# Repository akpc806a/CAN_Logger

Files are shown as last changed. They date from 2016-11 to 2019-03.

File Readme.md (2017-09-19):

# CAN Bus Logger / Playback Device with SD-card

The device can be used to log data from any CAN-bus based application: vehicle, automation, robotics, etc. The log is stored in comma separated text file (CSV) and each log entry (CAN-message) has a time stamp. It also has playback function, i.e. can play recorded file back onto a CAN bus, turning the device into a CAN bus simulator. The logger is an ideal solution for applications where small, cheap and simple device is needed to record CAN-bus activity without any additional hardware.

## Features

- The device has only one start/stop button, and all the settings are stored in configuration text file on SD card. No external PC or smartphone is required for logger operation.
- Bitrates up to 1 Mbps (any non-standard baud rate supported), supports CAN 2.0A (11-Bit ID) and CAN 2.0B (29-Bit ID).
- Optional message filtering based on ID mask matching.
- Selectable listen-only mode (without CAN bus acknowledge).
- Three LEDs for indication of logger status.
- Playback function with time accuracy of 3 ms.
- Open source and open hardware project.

## Specification

- Support for up to 32GB micro-SD cards (FAT32), for best results the UHS Speed Class 1 (U1) SD card recommended.
- Power supply voltage: from +5V to +20V DC.
- Dimensions: 48.26 x 20.85 mm (1.9 x 0.82 in).
- Microcontroller: STM32F405RGT6 (ARM Cortex M4).

## Where to buy ready made device

- [My Tindie store](https://www.tindie.com/products/akpc806a/can-bus-logger-with-sd-card/)
- [eBay](https://www.ebay.com/sch/i.html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)

N|Solid

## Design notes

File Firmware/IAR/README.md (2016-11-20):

This is project for IAR 6.50.3.4757 based on ChibiOS 2.6.7 RTOS for CAN bus logger

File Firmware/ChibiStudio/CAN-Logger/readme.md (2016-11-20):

How to build:
- download and install ChibiStudio_Preview17
- place project to [ChibiStudio]\chibios161\demos\STM32
- launch "Chibi Studio GCC 4.9"
- File>Import, select General>Existing Projects into Workspace, click Next
- Select root directory, Browse... point to project folder [ChibiStudio]\chibios161\demos\STM32
- check CAN-Logger, click Finish
- wait a little bit until Eclipse recognizes the project
- right click: Build project

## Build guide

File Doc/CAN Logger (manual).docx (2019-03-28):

# CAN Bus logger with SD-card

# 1. What is it?

This is just simple logger which writes everything from CAN bus to text file on a micro SD card. It has following features:

      - Easy to use: Only one start/stop button and all the settings are stored in configuration text file on the SD card.
      - Optional message filtering based on ID mask matching.
      - Selectable listen-only mode (without CAN bus acknowledge).
      - Three LEDs for indication of logger.

Device specification:

Parameter | Value
Power supply voltage | 5.5V-20V
Current consumption | 60mA at 5V input
CAN baudrate | up to 1Mbps (any non-standard baudrate supported)
CAN ID mask filters | 1
Microcontroller | STM32F405RGT6
CAN transceiver | SN65HVD232DR
PCB size | 48.26 mm x 20.85 mm (1.9 in x 0.82 in)

Board connections:

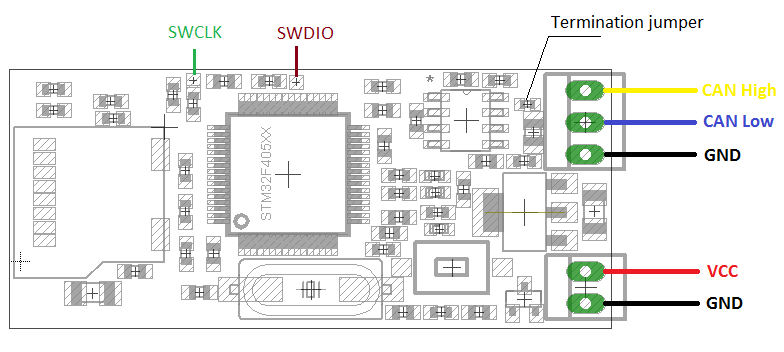
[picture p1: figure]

LEDs:

- Green: power on, also toggling every time when the CAN receives and accepts messages.
- Blue: blinks each time when block of data has been written to the SD card.
- Red: fault indication (see below).

# 2. How to start

- Connect CAN bus.
- Connect power supply (make sure the correct voltage range).
- Place Config.txt file to the root folder of SD card (here is example (https://raw.githubusercontent.com/akpc806a/CAN_Logger/master/Doc/Test/Config.txt) of the file for ODB). It is recommended to choose fastest SD card (UHS Speed Class 1 / U1) and format SD card before use in logger.
- Insert SD card.
- Press "START" button to start log
- The blue LED should blinkperiodically (with speed dependant from writing rate).
- Press "START" button again to stop the log.
- The log file placed to root folder and has name in format: N.csv, where N is number between 0 and 99999999. The next time logger will increment a file name number and write to N+1.csv, for example if there are files 0.csv, 1.csv and 2.csv, then the next written file will be 3.csv.

# 3. Configuration file format

Parameter | Parameter format | Meaning
baud | Decimal | CAN bus baudrate in kbps
ack_en | 0 or 1 | If 1 then CAN logger is responding with ACK slot on reception of a valid CAN frame. Set to 0 for silent (listen-only) mode.
id_filter_mask | Hex | Bit mask for ID filtering
id_filter_value | Hex | Expected value for ID
log_std | 0 or 1 | Messages with standard (11 bit) ID are accepted if set to 1
log_ext | 0 or 1 | Messages with extended (24 bit) ID are accepted if set to 1
timestamp | 0 or 1 | If 1 then every record in log file has a timestamp (in milliseconds)
circular_write | 0 or 1 | This will delete oldest file if there is less than 10% of free space on disk (please be aware of possible logging gap up about to 1s)
start_on_power | 0 or 1 | Recording will start immediately on power on (no push button needed)
start_on_CAN | 0 or 1 | This will start logging when a CAN message with specific ID has been received (please give about 50-100ms to prepare file on disk for record)
stop_on_CAN | 0 or 1 | This will stop logging when a CAN message with specific ID has been received
start_frame_to_name | 0 or 1 | The data of the CAN message will be used for file name
start_id_value | 0 or 1 | Bit mask of ID filtering for CAN frame which starts logging
start_id_mask | 0 or 1 | Expected value of ID for CAN frame which starts logging
stop_id_value | 0 or 1 | Bit mask of ID filtering for CAN frame which stops logging
stop_id_mask | 0 or 1 | Expected value of ID for CAN frame which stops logging

Only baud is required, all other configuration parameters are optional (and equal to 0 by default).

The ID filter acceptance criterion is:

[CAN message ID] & id_filter_mask = id_filter_value & id_filter_mask

where & is bitwise logical and operator.

For example if id_filter_mask = A = 1010 binary and the id_filter_value = 2 = 0010 binary. It means that the bit #1 and bit #3 of CAN identifier will be checked, and the bit #1 is expected to be 1 and bit #3 to be 0. Thus only identifiers with a binary ending of …0X1X will be accepted by CAN1, i.e. in hex 0x?2, 0x?3, 0x?6, 0x?7.

Set id_filter_mask= 0 to disable the ID filter.

A message with specific ID will initiate start of logging when start_on_CAN defined to 1 and following is true:

[CAN message ID] & start_id_mask = start_id_value & start_id_mask

where & is bitwise logical and operator.

A message with specific ID will stop logging when stop_on_CAN defined to 1 and following is true:

[CAN message ID] & stop_id_mask = stop_id_value & stop_id_mask

where & is bitwise logical and operator.

The option start_frame_to_name can be used in conjunction with start_on_CAN. The lower 4 bits of all data bytes from the starting CAN message will form a new file name of log file. For example if the data for start CAN message defined by ID with start_id_value/start_id_mask is = {0x01, 0x02, 0x03, 0x04, 0x05, 0x06, 0x07, 0x08}, then the new file name will be 12345678.csv;

# 4. Log file format

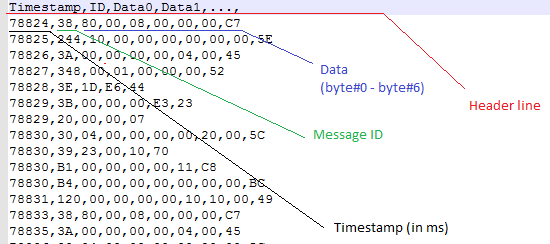
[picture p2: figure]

# 5. Faults and indication

- If red LED and blue LED are both on just after pressing "START" button, then this is a configuration text file problem; check configuration file.
- If red LED is on during logging, then this is either data buffer overflow or SD card problem. Check if there is enough free space on SD card or SD card has acceptable writing speed rate.

# 6. CAN bus termination

Please note that the 120 ohm termination resistor is permanently placed on board. There is no configurable option for it. However, there is a jumper as 0402 resistor which is possible to unmount for termination disconnection.

If the bus already has termination at the both ends, then you may consider removing on-board termination. However, for most application it’s ok to leave it (for example when connecting to vehicle OBD-II diagnostic connector).

# 7. CAN bus simulator (playback from file)

There is an experimental function implemented to play back recorded data onto a CAN bus, turning device into a CAN bus simulator.

Place recorded log to SD card root folder, rename it to Play.csv. Press "START" button, the device will read Play.csv file line by line and transmit all recorded CAN messages back to the bus. After completion of transmission the device will be switched to standard logger mode.

- Playback file will be transmitted with the baudrate from Config.txt file.

- Playback file should be time-stamped (i.e. recorded with timestamp=1 option).

- Playback file should contain a header, i.e. first line of the file will be skipped.

- By default, all messages will be send out using standard (11-bit) identifier, if the identifier value from file fits into 11 bit, otherwise it will be send as 24 bit (if it does require more than 11 bits)

- You can enforce the usage of extended identifiers only by setting log_std=0 in Config.txt

- The green LED will be off during playback, the blue LED will toggle every time when the message has been sent, red LED will be on if any faults occurred.

Limitations:

- All messages should be acknowledged from the CAN bus side.

- It is not exactly time accurate because timestamp has 1 ms granularity.

- The only way to exit playback mode in case if it’s stuck (for example due to bus fault), is to power cycle the device.

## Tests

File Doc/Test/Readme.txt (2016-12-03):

This is use case data for OBD-II diagnostic bus logging.
In parallel to the device the PCAN-USB Adapter (by PACN / Grid Connect) was connected and logging performed using PcanView software. Logging to SD card was started first, so there is portion of data at the beginning which is absent in PCAN log.
Then both logs were post-processed and compared with WinMerge. You can check the screenshot WinMerge.png of comparision.
No difference has been found.
The 'Config.txt' file used to configure logger device included.

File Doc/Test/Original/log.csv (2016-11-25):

Timestamp,ID,Data0,Data1,...,
78824,38,80,00,08,00,00,00,C7
78825,244,10,00,00,00,00,00,00,5E
78826,3A,00,00,00,00,04,00,45
78827,348,00,01,00,00,00,52
78828,3E,1D,E6,44
78829,3B,00,00,00,E3,23
78829,20,00,00,07
78830,30,04,00,00,00,00,20,00,5C
78830,39,23,00,10,70
78830,B1,00,00,00,00,11,C8
78830,B4,00,00,00,00,00,00,00,BC
78831,120,00,00,00,00,10,10,00,49
78833,38,80,00,08,00,00,00,C7
78835,3A,00,00,00,00,04,00,45
78836,30,04,00,00,00,00,20,00,5C
78837,B3,00,00,00,00,11,CA
78837,3E,1D,E6,44
78837,3B,00,00,00,E3,23
78838,39,23,00,10,70
78841,38,80,00,08,00,00,00,C7
78841,3CA,00,20,00,00,F2
78842,262,00,01,00,69
78842,20,00,00,07
78843,30,04,00,00,00,00,20,00,5C
78843,3A,00,00,00,00,04,00,45
78843,B1,00,00,00,00,11,C8
78843,B4,00,00,00,00,00,00,00,BC
78844,230,00,05,00,00,00,00,3E
78845,3E,1D,E6,44
78845,3B,00,00,00,E3,23
78846,39,23,00,10,70
78847,120,00,00,00,00,10,10,00,49
78847,3C8,00,34,00,00,04
78849,38,80,00,08,00,00,00,C7
78849,30,04,00,00,00,00,20,00,5C
78849,B3,00,00,00,00,11,CA
78850,244,10,00,00,00,00,00,00,5E
78851,3A,00,00,00,00,04,00,45
78853,3E,1D,E6,44
78853,3B,00,00,00,E3,23
78854,39,23,00,10,70
78855,20,00,00,07
78855,30,04,00,00,00,00,20,00,5C
78855,B1,00,00,00,00,11,C8
78856,B4,00,00,00,00,00,00,00,BC
78857,38,80,00,08,00,00,00,C7
78857,3CF,10,0F,1D,00,13
78859,3A,00,00,00,00,04,00,45
78861,3E,1D,E6,44
78861,3B,00,00,00,E3,23
78862,30,04,00,00,00,00,20,00,5C
78862,B3,00,00,00,00,11,CA
78862,262,00,01,00,69
78863,39,23,00,10,70
78863,120,00,00,00,00,10,10,00,49
78865,38,80,00,08,00,00,00,C7
78867,3A,00,00,00,00,04,00,45
78868,348,00,01,00,00,00,52
78868,20,00,00,07
78868,30,04,00,00,00,00,20,00,5C
78868,B1,00,00,00,00,11,C8
78868,B4,00,00,00,00,00,00,00,BC
78869,230,00,05,00,00,00,00,3E
78869,3B,00,00,00,E4,24
78869,3E,1D,E6,44
78871,39,23,00,10,70
78873,3C9,03,FF,21,02,9B,03,21,B8
78874,38,80,00,08,00,00,00,C7
78874,244,10,00,00,00,00,00,00,5E
78874,30,04,00,00,00,00,20,00,5C
78875,B3,00,00,00,00,11,CA
78876,3A,00,00,00,00,04,00,45
78877,3B,00,00,00,E4,24
78878,3E,1D,E6,44
78879,39,23,00,10,70
78880,120,00,00,00,00,10,10,00,49
78880,20,00,00,07
78881,30,04,00,00,00,00,20,00,5C
78881,B1,00,00,00,00,11,C8
78881,B4,00,00,00,00,00,00,00,BC
78881,3CB,64,64,00,81,11,10,3F
78882,38,80,00,08,00,00,00,C7
78882,521,23,00
78883,262,00,01,00,69
78884,3A,00,00,00,00,04,00,45
78885,3B,00,00,00,E3,23
78886,3E,1D,E6,44
78887,39,23,00,10,70
78887,30,04,00,00,00,00,20,00,5C
78888,B3,00,00,00,00,11,CA
78889,3CD,00,00,00,E2,B7
78890,38,80,00,08,00,00,00,C7
78892,3A,00,00,00,00,04,00,45
78893,20,00,00,07
78893,30,04,00,00,00,00,20,00,5C
78894,3B,00,00,00,E3,23
78894,B1,00,00,00,00,11,C8
78894,3E,1D,E6,44
78894,B4,00,00,00,00,00,00,00,BC
78894,230,00,05,00,00,00,00,3E
78895,554,58,41,42,4C,41,45,4E
78895,39,23,00,10,70
78896,120,00,00,00,00,10,10,00,49
78898,38,80,00,08,00,00,00,C7
78898,244,10,00,00,00,00,00,00,5E
78900,30,04,00,00,00,00,20,00,5C
78900,3A,00,00,00,00,04,00,45
78900,B3,00,00,00,00,11,CA
78901,3B,00,00,00,E3,23
78902,3E,1D,E6,44
78902,262,00,01,00,69
78903,39,23,00,10,70
78906,20,00,00,07
78906,30,04,00,00,00,00,20,00,5C
78906,38,80,00,08,00,00,00,C7
78907,B1,00,00,00,00,11,C8
78907,B4,00,00,00,00,00,00,00,BC
78908,3A,00,00,00,00,04,00,45
78909,348,00,01,00,00,00,52
78909,3B,00,00,00,E4,24
78910,3E,1D,E6,44
78912,39,23,00,10,70
78912,120,00,00,00,00,10,10,00,49
78913,30,04,00,00,00,00,20,00,5C
78913,B3,00,00,00,00,11,CA
78913,3C8,00,34,00,00,04
78915,38,80,00,08,00,00,00,C7
78917,3A,00,00,00,00,04,00,45
78917,3B,00,00,00,E4,24
78919,3E,1D,E6,44
78919,20,00,00,07
78919,30,04,00,00,00,00,20,00,5C
78919,B1,00,00,00,00,11,C8
78919,B4,00,00,00,00,00,00,00,BC
78920,230,00,05,00,00,00,00,3E
78920,39,23,00,10,70
78920,553,58,49,00,08,00,00,00
78922,262,00,01,00,69
78923,38,80,00,08,00,00,00,C7
78923,244,10,00,00,00,00,00,00,5E
78925,3A,00,00,00,00,04,00,45
78925,3B,00,00,00,E3,23
78926,30,04,00,00,00,00,20,00,5C
78926,B3,00,00,00,00,11,CA
78927,3E,1D,E6,44
78928,39,23,00,10,70
78929,120,00,00,00,00,10,10,00,49
78931,38,80,00,08,00,00,00,C7
78931,20,00,00,07
78932,30,04,00,00,00,00,20,00,5C
78932,B1,00,00,00,00,11,C8
78932,B4,00,00,00,00,00,00,00,BC
78933,3A,00,00,00,00,04,00,45
78933,3B,00,00,00,E3,23
78935,3E,1D,E6,44
78936,39,23,00,10,70
78938,30,04,00,00,00,00,20,00,5C
78938,B3,00,00,00,00,11,CA
78939,38,80,00,08,00,00,00,C7
78941,3A,00,00,00,00,04,00,45
78941,3B,00,00,00,E3,23
78941,3CA,00,20,00,00,F2
78942,262,00,01,00,69
78943,3E,1D,E6,44
78944,20,00,00,07
78944,30,04,00,00,00,00,20,00,5C
78945,39,23,00,10,70
78945,B1,00,00,00,00,11,C8
78945,B4,00,00,00,00,00,00,00,BC
78945,120,00,00,00,00,10,10,00,49
78946,230,00,05,00,00,00,00,3E
78946,4D0,10,00,02,02,00,00,00,00
78947,38,80,00,08,00,00,00,C7
78948,244,10,00,00,00,00,00,00,5E
78949,3A,00,00,00,00,04,00,45
78949,3B,00,00,00,E3,23
78950,348,00,01,00,00,00,52
78951,30,04,00,00,00,00,20,00,5C
78951,B3,00,00,00,00,11,CA
78951,3E,1D,E6,44
78953,39,23,00,10,70
78955,38,80,00,08,00,00,00,C7
78957,20,00,00,07
78957,30,04,00,00,00,00,20,00,5C
78957,3A,00,00,00,00,04,00,45
78958,3B,00,00,00,E3,23
78958,B1,00,00,00,00,11,C8
78958,B4,00,00,00,00,00,00,00,BC
78959,3E,1D,E6,44
78961,39,23,00,10,70
78962,120,00,00,00,00,10,10,00,49
78962,262,00,01,00,69
78964,38,80,00,08,00,00,00,C7
78964,30,04,00,00,00,00,20,00,5C
78964,B3,00,00,00,00,11,CA
78965,3B,00,00,00,E4,24
78966,3A,00,00,00,00,04,00,45
78968,3E,1D,E6,44
78969,39,23,00,10,70
78970,20,00,00,07
78970,30,04,00,00,00,00,20,00,5C
78970,B1,00,00,00,00,11,C8
78970,B4,00,00,00,00,00,00,00,BC
78971,230,00,05,00,00,00,00,3E
78972,38,80,00,08,00,00,00,C7
78972,244,10,00,00,00,00,00,00,5E
78973,56D,65,68,80,7F
78973,3B,00,00,00,E4,24
78974,3C9,03,FF,21,02,9B,03,21,B8
78974,3A,00,00,00,00,04,00,45
78976,3E,1D,E6,44
78976,30,04,00,00,00,00,20,00,5C
78977,B3,00,00,00,00,11,CA
78977,39,23,00,10,70
78978,120,00,00,00,00,10,10,00,49
78978,3C8,00,34,00,00,04
78980,38,80,00,08,00,00,00,C7
78981,3B,00,00,00,E4,24
78982,3CB,64,64,00,81,11,10,3F
78982,3A,00,00,00,00,04,00,45
78982,20,00,00,07
78983,30,04,00,00,00,00,20,00,5C
78983,B1,00,00,00,00,11,C8
78983,B4,00,00,00,00,00,00,00,BC
78983,262,00,01,00,69
78984,3E,1D,E6,44
78985,39,23,00,10,70
78987,52C,23,46
78988,38,80,00,08,00,00,00,C7
78988,3CF,10,0F,1D,00,13
78989,30,04,00,00,00,00,20,00,5C
78990,3B,00,00,00,E3,23
78990,B3,00,00,00,00,11,CA
78990,3CD,00,00,00,E3,B8
78990,3A,00,00,00,00,04,00,45
78991,348,00,01,00,00,00,52
78992,3E,1D,E6,44
78994,39,23,00,10,70
78994,120,00,00,00,00,10,10,00,49
78995,20,00,00,07
78996,30,04,00,00,00,00,20,00,5C
78996,B1,00,00,00,00,11,C8
78996,B4,00,00,00,00,00,00,00,BC
78996,230,00,05,00,00,00,00,3E
78996,38,80,00,08,00,00,00,C7
78997,244,10,00,00,00,00,00,00,5E
78997,3B,00,00,00,E3,23
78998,5D4,23,00
78998,3A,00,00,00,00,04,00,45
79000,3E,1D,E6,44
79002,39,23,00,10,70
79002,30,04,00,00,00,00,20,00,5C
79002,B3,00,00,00,00,11,CA
79002,262,00,01,00,69
79005,38,80,00,08,00,00,00,C7
79005,3B,00,00,00,E3,23
79007,3A,00,00,00,00,04,00,45
79007,5F8,23,04
79008,20,00,00,07
79008,30,04,00,00,00,00,20,00,5C
79008,B1,00,00,00,00,11,C8
79009,B4,00,00,00,00,00,00,00,BC
79009,3E,1D,E6,44
79010,39,23,00,10,70
79011,120,00,00,00,00,10,10,00,49
79013,38,80,00,08,00,00,00,C7
79013,3B,00,00,00,E4,24
79015,30,04,00,00,00,00,20,00,5C
79015,3A,00,00,00,00,04,00,45
79015,B3,00,00,00,00,11,CA
79017,3E,1D,E6,44
79018,39,23,00,10,70
79021,20,00,00,07
79021,30,04,00,00,00,00,20,00,5C
79021,38,80,00,08,00,00,00,C7
79021,3B,00,00,00,E4,24
79022,B1,00,00,00,00,11,C8
79022,B4,00,00,00,00,00,00,00,BC
79022,244,10,00,00,00,00,00,00,5E
79022,230,00,05,00,00,00,00,3E
79022,262,00,01,00,69
79023,3A,00,00,00,00,04,00,45
79025,3E,1D,E6,44
79026,39,23,00,10,70
79027,120,00,00,00,00,10,10,00,49
79027,30,04,00,00,00,00,20,00,5C
79028,B3,00,00,00,00,11,CA
79029,38,80,00,08,00,00,00,C7
79029,3B,00,00,00,E3,23
79031,3A,00,00,00,00,04,00,45
79031,348,00,01,00,00,00,52
79033,3E,1D,E6,44
79033,20,00,00,07
79034,30,04,00,00,00,00,20,00,5C
79034,B1,00,00,00,00,11,C8
79034,B4,00,00,00,00,00,00,00,BC
79035,39,23,00,10,70
79037,38,80,00,08,00,00,00,C7
79038,3B,00,00,00,E3,23
79039,3A,00,00,00,00,04,00,45
79040,30,04,00,00,00,00,20,00,5C
79041,B3,00,00,00,00,11,CA
79041,3E,1D,E6,44
79042,3CA,00,20,00,00,F2
79042,262,00,01,00,69
79043,39,23,00,10,70
79044,120,00,00,00,00,10,10,00,49
79044,3C8,00,34,00,00,04
79045,3B,00,00,00,E3,23
79046,38,80,00,08,00,00,00,C7
79046,244,10,00,00,00,00,00,00,5E
79046,20,00,00,07
79046,30,04,00,00,00,00,20,00,5C
79047,B1,00,00,00,00,11,C8
79047,B4,00,00,00,00,00,00,00,BC
79047,230,00,05,00,00,00,00,3E
79048,3A,00,00,00,00,04,00,45
79050,3E,1D,E6,44
79051,39,23,00,10,70
79053,30,04,00,00,00,00,20,00,5C
79053,B3,00,00,00,00,11,CA
79053,3B,00,00,00,E3,23
79054,38,80,00,08,00,00,00,C7
79056,3A,00,00,00,00,04,00,45
79058,3E,1D,E6,44
79059,20,00,00,07
79059,30,04,00,00,00,00,20,00,5C
79059,39,23,00,10,70
79060,B1,00,00,00,00,11,C8
79060,B4,00,00,00,00,00,00,00,BC
79060,120,00,00,00,00,10,10,00,49
79061,3B,00,00,00,E3,23
79062,38,80,00,08,00,00,00,C7
79062,262,00,01,00,69
79064,3A,00,00,00,00,04,00,45
79066,30,04,00,00,00,00,20,00,5C
79066,B3,00,00,00,00,11,CA
79066,3E,1D,E6,44
79067,39,23,00,10,70
79069,3B,00,00,00,E4,24
79070,38,80,00,08,00,00,00,C7
79070,244,10,00,00,00,00,00,00,5E
79072,20,00,00,07
79072,30,04,00,00,00,00,20,00,5C
79072,3A,00,00,00,00,04,00,45
79072,B1,00,00,00,00,11,C8
79073,B4,00,00,00,00,00,00,00,BC
79073,348,00,01,00,00,00,52
79073,230,00,05,00,00,00,00,3E
79073,3C9,03,FF,21,02,9B,03,21,B8
79074,3E,1D,E6,44
79074,5CC,24,01,C0
79076,39,23,00,10,70
79076,120,00,00,00,00,10,10,00,49
79077,3B,00,00,00,E4,24
79078,30,04,00,00,00,00,20,00,5C
79079,38,80,00,08,00,00,00,C7
79079,B3,00,00,00,00,11,CA
79080,3A,00,00,00,00,04,00,45
79081,3CB,64,64,00,81,11,10,3F
79082,262,00,01,00,69
79082,3E,1D,E6,44
79084,39,23,00,10,70
79084,20,00,00,07
79085,30,04,00,00,00,00,20,00,5C
79085,B1,00,00,00,00,11,C8
79085,B4,00,00,00,00,00,00,00,BC
79085,3B,00,00,00,E3,23
79087,38,80,00,08,00,00,00,C7
79089,3A,00,00,00,00,04,00,45
79089,3CD,00,00,00,E3,B8
79091,3E,1D,E6,44
79091,30,04,00,00,00,00,20,00,5C
79091,B3,00,00,00,00,11,CA
79092,39,23,00,10,70
79093,120,00,00,00,00,10,10,00,49
79093,3B,00,00,00,E3,23
79095,38,80,00,08,00,00,00,C7
79095,244,10,00,00,00,00,00,00,5E
79097,3A,00,00,00,00,04,00,45
79097,20,00,00,07
79097,30,04,00,00,00,00,20,00,5C
79098,B1,00,00,00,00,11,C8
79098,B4,00,00,00,00,00,00,00,BC
79098,230,00,05,00,00,00,00,3E
79099,3E,1D,E6,44
79100,39,23,00,10,70
79101,3B,00,00,00,E3,23
79102,262,00,01,00,69
79103,38,80,00,08,00,00,00,C7
79104,30,04,00,00,00,00,20,00,5C
79104,B3,00,00,00,00,11,CA
79105,3A,00,00,00,00,04,00,45
79107,3E,1D,E6,44
79108,39,23,00,10,70
79109,120,00,00,00,00,10,10,00,49
79109,3C8,00,34,00,00,04
79110,3B,00,00,00,E4,24
79110,20,00,00,07
79110,30,04,00,00,00,00,20,00,5C
79110,B1,00,00,00,00,11,C8
79111,B4,00,00,00,00,00,00,00,BC
79111,38,80,00,08,00,00,00,C7
79113,3A,00,00,00,00,04,00,45
79113,348,00,01,00,00,00,52
79115,3E,1D,E6,44
79116,39,23,00,10,70
79117,30,04,00,00,00,00,20,00,5C
79117,B3,00,00,00,00,11,CA
79117,3B,00,00,00,E3,23
79119,38,80,00,08,00,00,00,C7
79120,244,10,00,00,00,00,00,00,5E
79120,3CF,10,0F,1D,00,13
79121,3A,00,00,00,00,04,00,45
79122,262,00,01,00,69
79123,20,00,00,07
79123,30,04,00,00,00,00,20,00,5C
79123,B1,00,00,00,00,11,C8
79123,B4,00,00,00,00,00,00,00,BC
79123,3E,1D,E6,44
79124,230,00,05,00,00,00,00,3E
79125,39,23,00,10,70
79125,3B,00,00,00,E3,23
79126,120,00,00,00,00,10,10,00,49
79128,38,80,00,08,00,00,00,C7
79129,30,04,00,00,00,00,20,00,5C
79130,3A,00,00,00,00,04,00,45
79130,B3,00,00,00,00,11,CA
79130,591,25,A0,1C,06
79132,3E,1D,E6,44
79133,39,23,00,10,70
79133,3B,00,00,00,E3,23
79134,4C1,01,00,09,00,00,00,00,00
79135,20,00,00,07
79136,30,04,00,00,00,00,20,00,5C
79136,38,80,00,08,00,00,00,C7
79136,B1,00,00,00,00,11,C8
79136,B4,00,00,00,00,00,00,00,BC
79138,3A,00,00,00,00,04,00,45
79140,3E,1D,E6,44
79141,39,23,00,10,70
79141,3B,00,00,00,E3,23
79142,120,00,00,00,00,10,10,00,49
79142,3CA,00,20,00,00,F2
79142,30,04,00,00,00,00,20,00,5C
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

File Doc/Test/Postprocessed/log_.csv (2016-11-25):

0038,80,00,08,00,00,00,C7
0244,10,00,00,00,00,00,00,5E
003A,00,00,00,00,04,00,45
0348,00,01,00,00,00,52
003E,1D,E6,44
003B,00,00,00,E3,23
0020,00,00,07
0030,04,00,00,00,00,20,00,5C
0039,23,00,10,70
00B1,00,00,00,00,11,C8
00B4,00,00,00,00,00,00,00,BC
0120,00,00,00,00,10,10,00,49
0038,80,00,08,00,00,00,C7
003A,00,00,00,00,04,00,45
0030,04,00,00,00,00,20,00,5C
00B3,00,00,00,00,11,CA
003E,1D,E6,44
003B,00,00,00,E3,23
0039,23,00,10,70
0038,80,00,08,00,00,00,C7
03CA,00,20,00,00,F2
0262,00,01,00,69
0020,00,00,07
0030,04,00,00,00,00,20,00,5C
003A,00,00,00,00,04,00,45
00B1,00,00,00,00,11,C8
00B4,00,00,00,00,00,00,00,BC
0230,00,05,00,00,00,00,3E
003E,1D,E6,44
003B,00,00,00,E3,23
0039,23,00,10,70
0120,00,00,00,00,10,10,00,49
03C8,00,34,00,00,04
0038,80,00,08,00,00,00,C7
0030,04,00,00,00,00,20,00,5C
00B3,00,00,00,00,11,CA
0244,10,00,00,00,00,00,00,5E
003A,00,00,00,00,04,00,45
003E,1D,E6,44
003B,00,00,00,E3,23
0039,23,00,10,70
0020,00,00,07
0030,04,00,00,00,00,20,00,5C
00B1,00,00,00,00,11,C8
00B4,00,00,00,00,00,00,00,BC
0038,80,00,08,00,00,00,C7
03CF,10,0F,1D,00,13
003A,00,00,00,00,04,00,45
003E,1D,E6,44
003B,00,00,00,E3,23
0030,04,00,00,00,00,20,00,5C
00B3,00,00,00,00,11,CA
0262,00,01,00,69
0039,23,00,10,70
0120,00,00,00,00,10,10,00,49
0038,80,00,08,00,00,00,C7
003A,00,00,00,00,04,00,45
0348,00,01,00,00,00,52
0020,00,00,07
0030,04,00,00,00,00,20,00,5C
00B1,00,00,00,00,11,C8
00B4,00,00,00,00,00,00,00,BC
0230,00,05,00,00,00,00,3E
003B,00,00,00,E4,24
003E,1D,E6,44
0039,23,00,10,70
03C9,03,FF,21,02,9B,03,21,B8
0038,80,00,08,00,00,00,C7
0244,10,00,00,00,00,00,00,5E
0030,04,00,00,00,00,20,00,5C
00B3,00,00,00,00,11,CA
003A,00,00,00,00,04,00,45
003B,00,00,00,E4,24
003E,1D,E6,44
0039,23,00,10,70
0120,00,00,00,00,10,10,00,49
0020,00,00,07
0030,04,00,00,00,00,20,00,5C
00B1,00,00,00,00,11,C8
00B4,00,00,00,00,00,00,00,BC
03CB,64,64,00,81,11,10,3F
0038,80,00,08,00,00,00,C7
0521,23,00
0262,00,01,00,69
003A,00,00,00,00,04,00,45
003B,00,00,00,E3,23
003E,1D,E6,44
0039,23,00,10,70
0030,04,00,00,00,00,20,00,5C
00B3,00,00,00,00,11,CA
03CD,00,00,00,E2,B7
0038,80,00,08,00,00,00,C7
003A,00,00,00,00,04,00,45
0020,00,00,07
0030,04,00,00,00,00,20,00,5C
003B,00,00,00,E3,23
00B1,00,00,00,00,11,C8
003E,1D,E6,44
00B4,00,00,00,00,00,00,00,BC
0230,00,05,00,00,00,00,3E
0554,58,41,42,4C,41,45,4E
0039,23,00,10,70
0120,00,00,00,00,10,10,00,49
0038,80,00,08,00,00,00,C7
0244,10,00,00,00,00,00,00,5E
0030,04,00,00,00,00,20,00,5C
003A,00,00,00,00,04,00,45
00B3,00,00,00,00,11,CA
003B,00,00,00,E3,23
003E,1D,E6,44
0262,00,01,00,69
0039,23,00,10,70
0020,00,00,07
0030,04,00,00,00,00,20,00,5C
0038,80,00,08,00,00,00,C7
00B1,00,00,00,00,11,C8
00B4,00,00,00,00,00,00,00,BC
003A,00,00,00,00,04,00,45
0348,00,01,00,00,00,52
003B,00,00,00,E4,24
003E,1D,E6,44
0039,23,00,10,70
0120,00,00,00,00,10,10,00,49
0030,04,00,00,00,00,20,00,5C
00B3,00,00,00,00,11,CA
03C8,00,34,00,00,04
0038,80,00,08,00,00,00,C7
003A,00,00,00,00,04,00,45
003B,00,00,00,E4,24
003E,1D,E6,44
0020,00,00,07
0030,04,00,00,00,00,20,00,5C
00B1,00,00,00,00,11,C8
00B4,00,00,00,00,00,00,00,BC
0230,00,05,00,00,00,00,3E
0039,23,00,10,70
0553,58,49,00,08,00,00,00
0262,00,01,00,69
0038,80,00,08,00,00,00,C7
0244,10,00,00,00,00,00,00,5E
003A,00,00,00,00,04,00,45
003B,00,00,00,E3,23
0030,04,00,00,00,00,20,00,5C
00B3,00,00,00,00,11,CA
003E,1D,E6,44
0039,23,00,10,70
0120,00,00,00,00,10,10,00,49
0038,80,00,08,00,00,00,C7
0020,00,00,07
0030,04,00,00,00,00,20,00,5C
00B1,00,00,00,00,11,C8
00B4,00,00,00,00,00,00,00,BC
003A,00,00,00,00,04,00,45
003B,00,00,00,E3,23
003E,1D,E6,44
0039,23,00,10,70
0030,04,00,00,00,00,20,00,5C
00B3,00,00,00,00,11,CA
0038,80,00,08,00,00,00,C7
003A,00,00,00,00,04,00,45
003B,00,00,00,E3,23
03CA,00,20,00,00,F2
0262,00,01,00,69
003E,1D,E6,44
0020,00,00,07
0030,04,00,00,00,00,20,00,5C
0039,23,00,10,70
00B1,00,00,00,00,11,C8
00B4,00,00,00,00,00,00,00,BC
0120,00,00,00,00,10,10,00,49
0230,00,05,00,00,00,00,3E
04D0,10,00,02,02,00,00,00,00
0038,80,00,08,00,00,00,C7
0244,10,00,00,00,00,00,00,5E
003A,00,00,00,00,04,00,45
003B,00,00,00,E3,23
0348,00,01,00,00,00,52
0030,04,00,00,00,00,20,00,5C
00B3,00,00,00,00,11,CA
003E,1D,E6,44
0039,23,00,10,70
0038,80,00,08,00,00,00,C7
0020,00,00,07
0030,04,00,00,00,00,20,00,5C
003A,00,00,00,00,04,00,45
003B,00,00,00,E3,23
00B1,00,00,00,00,11,C8
00B4,00,00,00,00,00,00,00,BC
003E,1D,E6,44
0039,23,00,10,70
0120,00,00,00,00,10,10,00,49
0262,00,01,00,69
0038,80,00,08,00,00,00,C7
0030,04,00,00,00,00,20,00,5C
00B3,00,00,00,00,11,CA
003B,00,00,00,E4,24
003A,00,00,00,00,04,00,45
003E,1D,E6,44
0039,23,00,10,70
0020,00,00,07
0030,04,00,00,00,00,20,00,5C
00B1,00,00,00,00,11,C8
00B4,00,00,00,00,00,00,00,BC
0230,00,05,00,00,00,00,3E
0038,80,00,08,00,00,00,C7
0244,10,00,00,00,00,00,00,5E
056D,65,68,80,7F
003B,00,00,00,E4,24
03C9,03,FF,21,02,9B,03,21,B8
003A,00,00,00,00,04,00,45
003E,1D,E6,44
0030,04,00,00,00,00,20,00,5C
00B3,00,00,00,00,11,CA
0039,23,00,10,70
0120,00,00,00,00,10,10,00,49
03C8,00,34,00,00,04
0038,80,00,08,00,00,00,C7
003B,00,00,00,E4,24
03CB,64,64,00,81,11,10,3F
003A,00,00,00,00,04,00,45
0020,00,00,07
0030,04,00,00,00,00,20,00,5C
00B1,00,00,00,00,11,C8
00B4,00,00,00,00,00,00,00,BC
0262,00,01,00,69
003E,1D,E6,44
0039,23,00,10,70
052C,23,46
0038,80,00,08,00,00,00,C7
03CF,10,0F,1D,00,13
0030,04,00,00,00,00,20,00,5C
003B,00,00,00,E3,23
00B3,00,00,00,00,11,CA
03CD,00,00,00,E3,B8
003A,00,00,00,00,04,00,45
0348,00,01,00,00,00,52
003E,1D,E6,44
0039,23,00,10,70
0120,00,00,00,00,10,10,00,49
0020,00,00,07
0030,04,00,00,00,00,20,00,5C
00B1,00,00,00,00,11,C8
00B4,00,00,00,00,00,00,00,BC
0230,00,05,00,00,00,00,3E
0038,80,00,08,00,00,00,C7
0244,10,00,00,00,00,00,00,5E
003B,00,00,00,E3,23
05D4,23,00
003A,00,00,00,00,04,00,45
003E,1D,E6,44
0039,23,00,10,70
0030,04,00,00,00,00,20,00,5C
00B3,00,00,00,00,11,CA
0262,00,01,00,69
0038,80,00,08,00,00,00,C7
003B,00,00,00,E3,23
003A,00,00,00,00,04,00,45
05F8,23,04
0020,00,00,07
0030,04,00,00,00,00,20,00,5C
00B1,00,00,00,00,11,C8
00B4,00,00,00,00,00,00,00,BC
003E,1D,E6,44
0039,23,00,10,70
0120,00,00,00,00,10,10,00,49
0038,80,00,08,00,00,00,C7
003B,00,00,00,E4,24
0030,04,00,00,00,00,20,00,5C
003A,00,00,00,00,04,00,45
00B3,00,00,00,00,11,CA
003E,1D,E6,44
0039,23,00,10,70
0020,00,00,07
0030,04,00,00,00,00,20,00,5C
0038,80,00,08,00,00,00,C7
003B,00,00,00,E4,24
00B1,00,00,00,00,11,C8
00B4,00,00,00,00,00,00,00,BC
0244,10,00,00,00,00,00,00,5E
0230,00,05,00,00,00,00,3E
0262,00,01,00,69
003A,00,00,00,00,04,00,45
003E,1D,E6,44
0039,23,00,10,70
0120,00,00,00,00,10,10,00,49
0030,04,00,00,00,00,20,00,5C
00B3,00,00,00,00,11,CA
0038,80,00,08,00,00,00,C7
003B,00,00,00,E3,23
003A,00,00,00,00,04,00,45
0348,00,01,00,00,00,52
003E,1D,E6,44
0020,00,00,07
0030,04,00,00,00,00,20,00,5C
00B1,00,00,00,00,11,C8
00B4,00,00,00,00,00,00,00,BC
0039,23,00,10,70
0038,80,00,08,00,00,00,C7
003B,00,00,00,E3,23
003A,00,00,00,00,04,00,45
0030,04,00,00,00,00,20,00,5C
00B3,00,00,00,00,11,CA
003E,1D,E6,44
03CA,00,20,00,00,F2
0262,00,01,00,69
0039,23,00,10,70
0120,00,00,00,00,10,10,00,49
03C8,00,34,00,00,04
003B,00,00,00,E3,23
0038,80,00,08,00,00,00,C7
0244,10,00,00,00,00,00,00,5E
0020,00,00,07
0030,04,00,00,00,00,20,00,5C
00B1,00,00,00,00,11,C8
00B4,00,00,00,00,00,00,00,BC
0230,00,05,00,00,00,00,3E
003A,00,00,00,00,04,00,45
003E,1D,E6,44
0039,23,00,10,70
0030,04,00,00,00,00,20,00,5C
00B3,00,00,00,00,11,CA
003B,00,00,00,E3,23
0038,80,00,08,00,00,00,C7
003A,00,00,00,00,04,00,45
003E,1D,E6,44
0020,00,00,07
0030,04,00,00,00,00,20,00,5C
0039,23,00,10,70
00B1,00,00,00,00,11,C8
00B4,00,00,00,00,00,00,00,BC
0120,00,00,00,00,10,10,00,49
003B,00,00,00,E3,23
0038,80,00,08,00,00,00,C7
0262,00,01,00,69
003A,00,00,00,00,04,00,45
0030,04,00,00,00,00,20,00,5C
00B3,00,00,00,00,11,CA
003E,1D,E6,44
0039,23,00,10,70
003B,00,00,00,E4,24
0038,80,00,08,00,00,00,C7
0244,10,00,00,00,00,00,00,5E
0020,00,00,07
0030,04,00,00,00,00,20,00,5C
003A,00,00,00,00,04,00,45
00B1,00,00,00,00,11,C8
00B4,00,00,00,00,00,00,00,BC
0348,00,01,00,00,00,52
0230,00,05,00,00,00,00,3E
03C9,03,FF,21,02,9B,03,21,B8
003E,1D,E6,44
05CC,24,01,C0
0039,23,00,10,70
0120,00,00,00,00,10,10,00,49
003B,00,00,00,E4,24
0030,04,00,00,00,00,20,00,5C
0038,80,00,08,00,00,00,C7
00B3,00,00,00,00,11,CA
003A,00,00,00,00,04,00,45
03CB,64,64,00,81,11,10,3F
0262,00,01,00,69
003E,1D,E6,44
0039,23,00,10,70
0020,00,00,07
0030,04,00,00,00,00,20,00,5C
00B1,00,00,00,00,11,C8
00B4,00,00,00,00,00,00,00,BC
003B,00,00,00,E3,23
0038,80,00,08,00,00,00,C7
003A,00,00,00,00,04,00,45
03CD,00,00,00,E3,B8
003E,1D,E6,44
0030,04,00,00,00,00,20,00,5C
00B3,00,00,00,00,11,CA
0039,23,00,10,70
0120,00,00,00,00,10,10,00,49
003B,00,00,00,E3,23
0038,80,00,08,00,00,00,C7
0244,10,00,00,00,00,00,00,5E
003A,00,00,00,00,04,00,45
0020,00,00,07
0030,04,00,00,00,00,20,00,5C
00B1,00,00,00,00,11,C8
00B4,00,00,00,00,00,00,00,BC
0230,00,05,00,00,00,00,3E
003E,1D,E6,44
0039,23,00,10,70
003B,00,00,00,E3,23
0262,00,01,00,69
0038,80,00,08,00,00,00,C7
0030,04,00,00,00,00,20,00,5C
00B3,00,00,00,00,11,CA
003A,00,00,00,00,04,00,45
003E,1D,E6,44
0039,23,00,10,70
0120,00,00,00,00,10,10,00,49
03C8,00,34,00,00,04
003B,00,00,00,E4,24
0020,00,00,07
0030,04,00,00,00,00,20,00,5C
00B1,00,00,00,00,11,C8
00B4,00,00,00,00,00,00,00,BC
0038,80,00,08,00,00,00,C7
003A,00,00,00,00,04,00,45
0348,00,01,00,00,00,52
003E,1D,E6,44
0039,23,00,10,70
0030,04,00,00,00,00,20,00,5C
00B3,00,00,00,00,11,CA
003B,00,00,00,E3,23
0038,80,00,08,00,00,00,C7
0244,10,00,00,00,00,00,00,5E
03CF,10,0F,1D,00,13
003A,00,00,00,00,04,00,45
0262,00,01,00,69
0020,00,00,07
0030,04,00,00,00,00,20,00,5C
00B1,00,00,00,00,11,C8
00B4,00,00,00,00,00,00,00,BC
003E,1D,E6,44
0230,00,05,00,00,00,00,3E
0039,23,00,10,70
003B,00,00,00,E3,23
0120,00,00,00,00,10,10,00,49
0038,80,00,08,00,00,00,C7
0030,04,00,00,00,00,20,00,5C
003A,00,00,00,00,04,00,45
00B3,00,00,00,00,11,CA
0591,25,A0,1C,06
003E,1D,E6,44
0039,23,00,10,70
003B,00,00,00,E3,23
04C1,01,00,09,00,00,00,00,00
0020,00,00,07
0030,04,00,00,00,00,20,00,5C
0038,80,00,08,00,00,00,C7
00B1,00,00,00,00,11,C8
00B4,00,00,00,00,00,00,00,BC
003A,00,00,00,00,04,00,45
003E,1D,E6,44
0039,23,00,10,70
003B,00,00,00,E3,23
0120,00,00,00,00,10,10,00,49
03CA,00,20,00,00,F2
0030,04,00,00,00,00,20,00,5C
00B3,00,00,00,00,11,CA
0262,00,01,00,69
0038,80,00,08,00,00,00,C7
0244,10,00,00,00,00,00,00,5E
003A,00,00,00,00,04,00,45
003E,1D,E6,44
0020,00,00,07
0030,04,00,00,00,00,20,00,5C
00B1,00,00,00,00,11,C8
00B4,00,00,00,00,00,00,00,BC
0230,00,05,00,00,00,00,3E
0039,23,00,10,70
003B,00,00,00,E3,23
0038,80,00,08,00,00,00,C7
003A,00,00,00,00,04,00,45
0348,00,01,00,00,00,52
0030,04,00,00,00,00,20,00,5C
00B3,00,00,00,00,11,CA
003E,1D,E6,44
003B,00,00,00,E3,23
0039,23,00,10,70
0120,00,00,00,00,10,10,00,49
0038,80,00,08,00,00,00,C7
0020,00,00,07
0030,04,00,00,00,00,20,00,5C
00B1,00,00,00,00,11,C8
00B4,00,00,00,00,00,00,00,BC
003A,00,00,00,00,04,00,45
0262,00,01,00,69
003E,1D,E6,44
003B,00,00,00,E4,24
0039,23,00,10,70
0030,04,00,00,00,00,20,00,5C
00B3,00,00,00,00,11,CA
0038,80,00,08,00,00,00,C7
0244,10,00,00,00,00,00,00,5E
003A,00,00,00,00,04,00,45
003E,1D,E6,44
003B,00,00,00,E4,24
03C9,03,FF,21,02,9B,03,21,B8
0020,00,00,07
0030,04,00,00,00,00,20,00,5C
0039,23,00,10,70
00B1,00,00,00,00,11,C8
00B4,00,00,00,00,00,00,00,BC
0120,00,00,00,00,10,10,00,49
0230,00,05,00,00,00,00,3E
03C8,00,34,00,00,04
0038,80,00,08,00,00,00,C7
003A,00,00,00,00,04,00,45
0030,04,00,00,00,00,20,00,5C
00B3,00,00,00,00,11,CA
003E,1D,E6,44
003B,00,00,00,E4,24
03CB,64,64,00,81,11,10,3F
0039,23,00,10,70
0521,23,00
0262,00,01,00,69
0038,80,00,08,00,00,00,C7
0020,00,00,07
0030,04,00,00,00,00,20,00,5C
00B1,00,00,00,00,11,C8
003A,00,00,00,00,04,00,45
00B4,00,00,00,00,00,00,00,BC
003E,1D,E6,44
003B,00,00,00,E4,24
03CD,00,00,00,E3,B8
0039,23,00,10,70
0120,00,00,00,00,10,10,00,49
0038,80,00,08,00,00,00,C7
0030,04,00,00,00,00,20,00,5C
00B3,00,00,00,00,11,CA
0244,10,00,00,00,00,00,00,5E
003A,00,00,00,00,04,00,45
0348,00,01,00,00,00,52
003E,1D,E6,44
003B,00,00,00,E3,23
0039,23,00,10,70
0020,00,00,07
0030,04,00,00,00,00,20,00,5C
00B1,00,00,00,00,11,C8
00B4,00,00,00,00,00,00,00,BC
0230,00,05,00,00,00,00,3E
0038,80,00,08,00,00,00,C7
0262,00,01,00,69
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

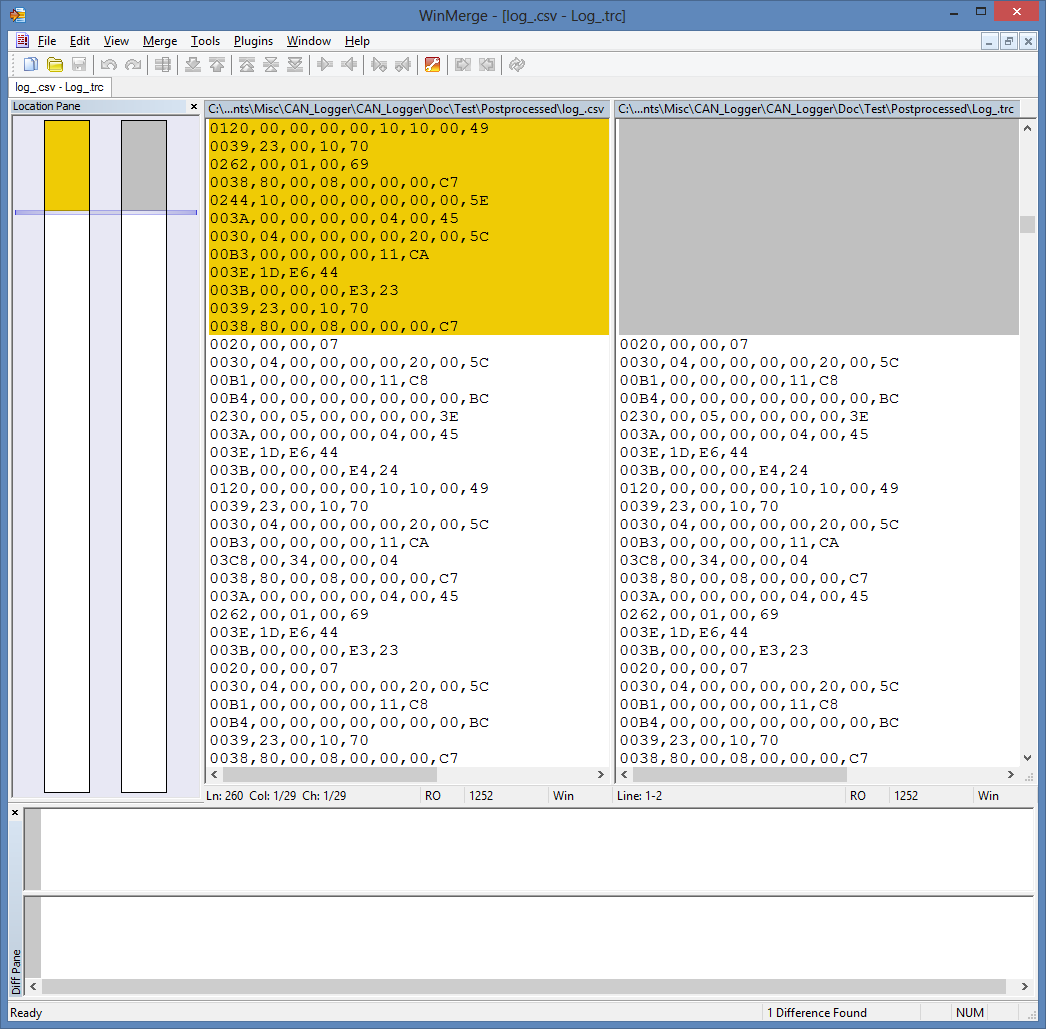
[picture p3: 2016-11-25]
Doc/Test/Postprocessed/WinMerge.png

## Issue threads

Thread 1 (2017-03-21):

Start logging automatically?

jakeogh, 2017-03-21:
Cool project! Works great. Can it capture messages as soon as it gets power? I spent a few min looking through the firmware and got lost.

akpc806a, 2017-03-21:
Hi Justin,

Thank you so much for your email.
Probably the simplest way to achieve that -- just short with wire the Start
button. I tested and it started recording after power on.

Sorry to ask, but if you have 30 seconds, can you please write a review for
this CAN logger. One word "works" is enough. :)

On Tue, Mar 21, 2017 at 12:41 AM, Justin Keogh <notifications@github.com>
wrote:

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

--
--
Alex Borisevich

jakeogh, 2017-03-22:
Ah, yes. Perfect.

NP! I made a tindie acct but don't see a way to add a review:
Totally works. I was logging HS CAN data as soon as I added Config.txt, plugged it in and pressed the button. Bought a second to monitor the medium speed bus.

akpc806a, 2017-03-22:
Hi Justin,

Sounds fantastic that it does work for you!

Just sent another one logger. The tracking number is 9400109699938295569865
.

Here is instruction how to leave feedback, hopefully its up to date:
https://tindie.zendesk.com/hc/en-us/articles/204864427-How-
do-I-leave-a-review-for-a-product-I-have-purchased-

On Tue, Mar 21, 2017 at 11:11 PM, Justin Keogh <notifications@github.com>
wrote:

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

--
--
Alex Borisevich

Closed 2017-04-04.

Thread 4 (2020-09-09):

Q: How do I flash the device?

axelriet, 2020-09-09:
Supposing I build the firmware, how do I flash it to the device? What do you recommend as SWD hardware that would work with ChibiStudio on a PC running Windows and allow flashing/debugging?

akpc806a, 2020-09-10:
Hello,
i usually use this type of dongles
https://www.amazon.com/HiLetgo-Emulator-Downloader-Programmer-STM32F103C8T6/dp/B07SQV6VLZ
which are clones of ST-Link V2.
You need to adjust setting in your IDE for SWD mode (not JTAG) and software reset.

The compiled binary file is here: https://sites.google.com/site/akpc806a/ch__wrap_files__delay_startup.hex
You can use ST-Link Utility for Windows or STM32CubeProg for Linux to flash this binary

axelriet, 2020-09-24:
Thanks!

Closed 2020-09-24.

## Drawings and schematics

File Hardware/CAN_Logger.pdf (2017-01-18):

# GND¹ k +3V³

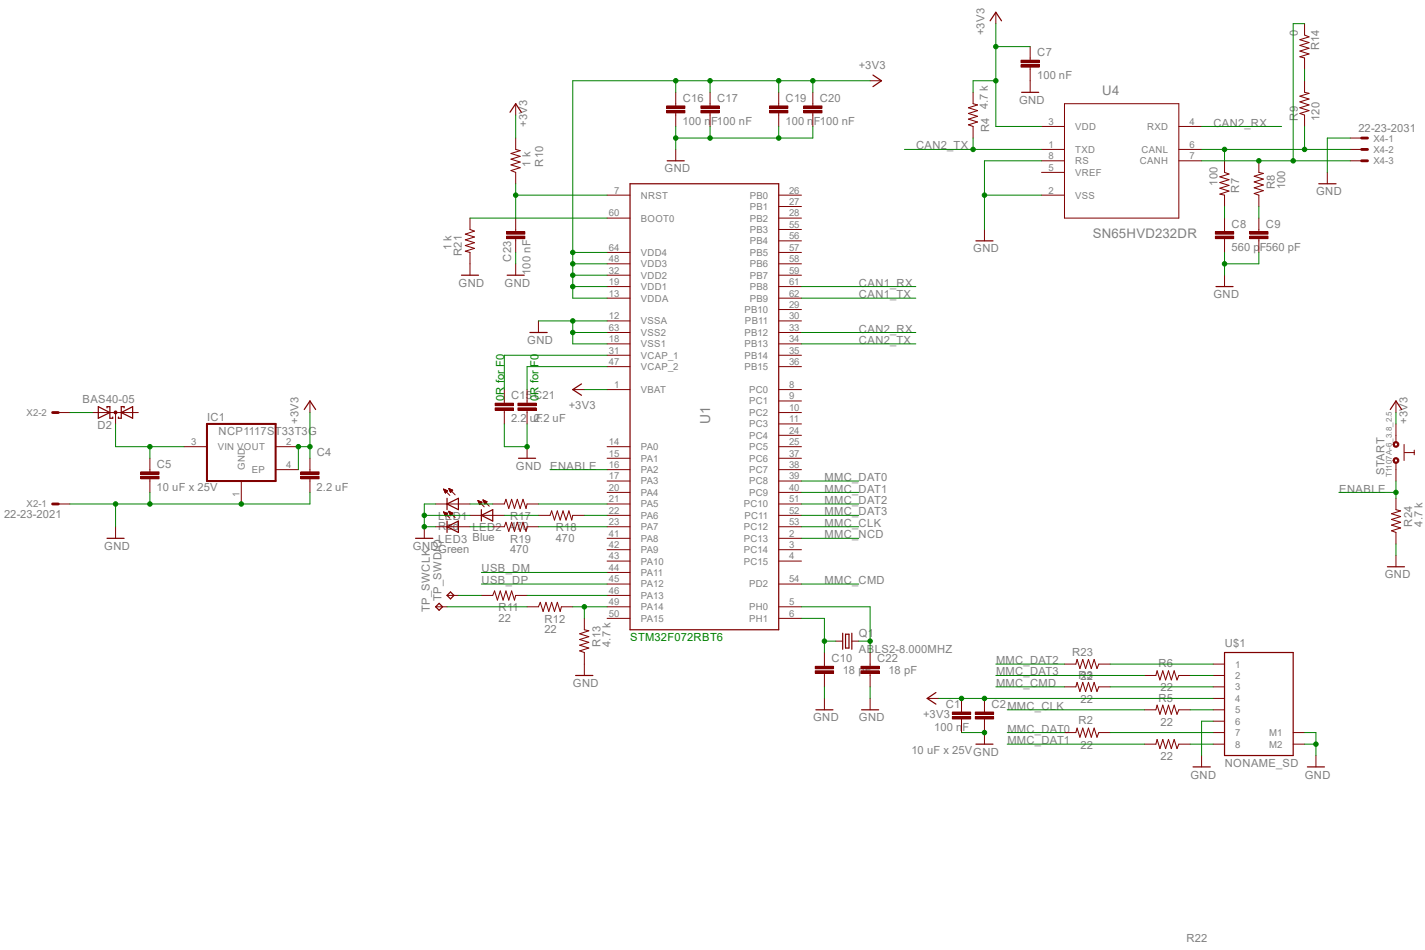
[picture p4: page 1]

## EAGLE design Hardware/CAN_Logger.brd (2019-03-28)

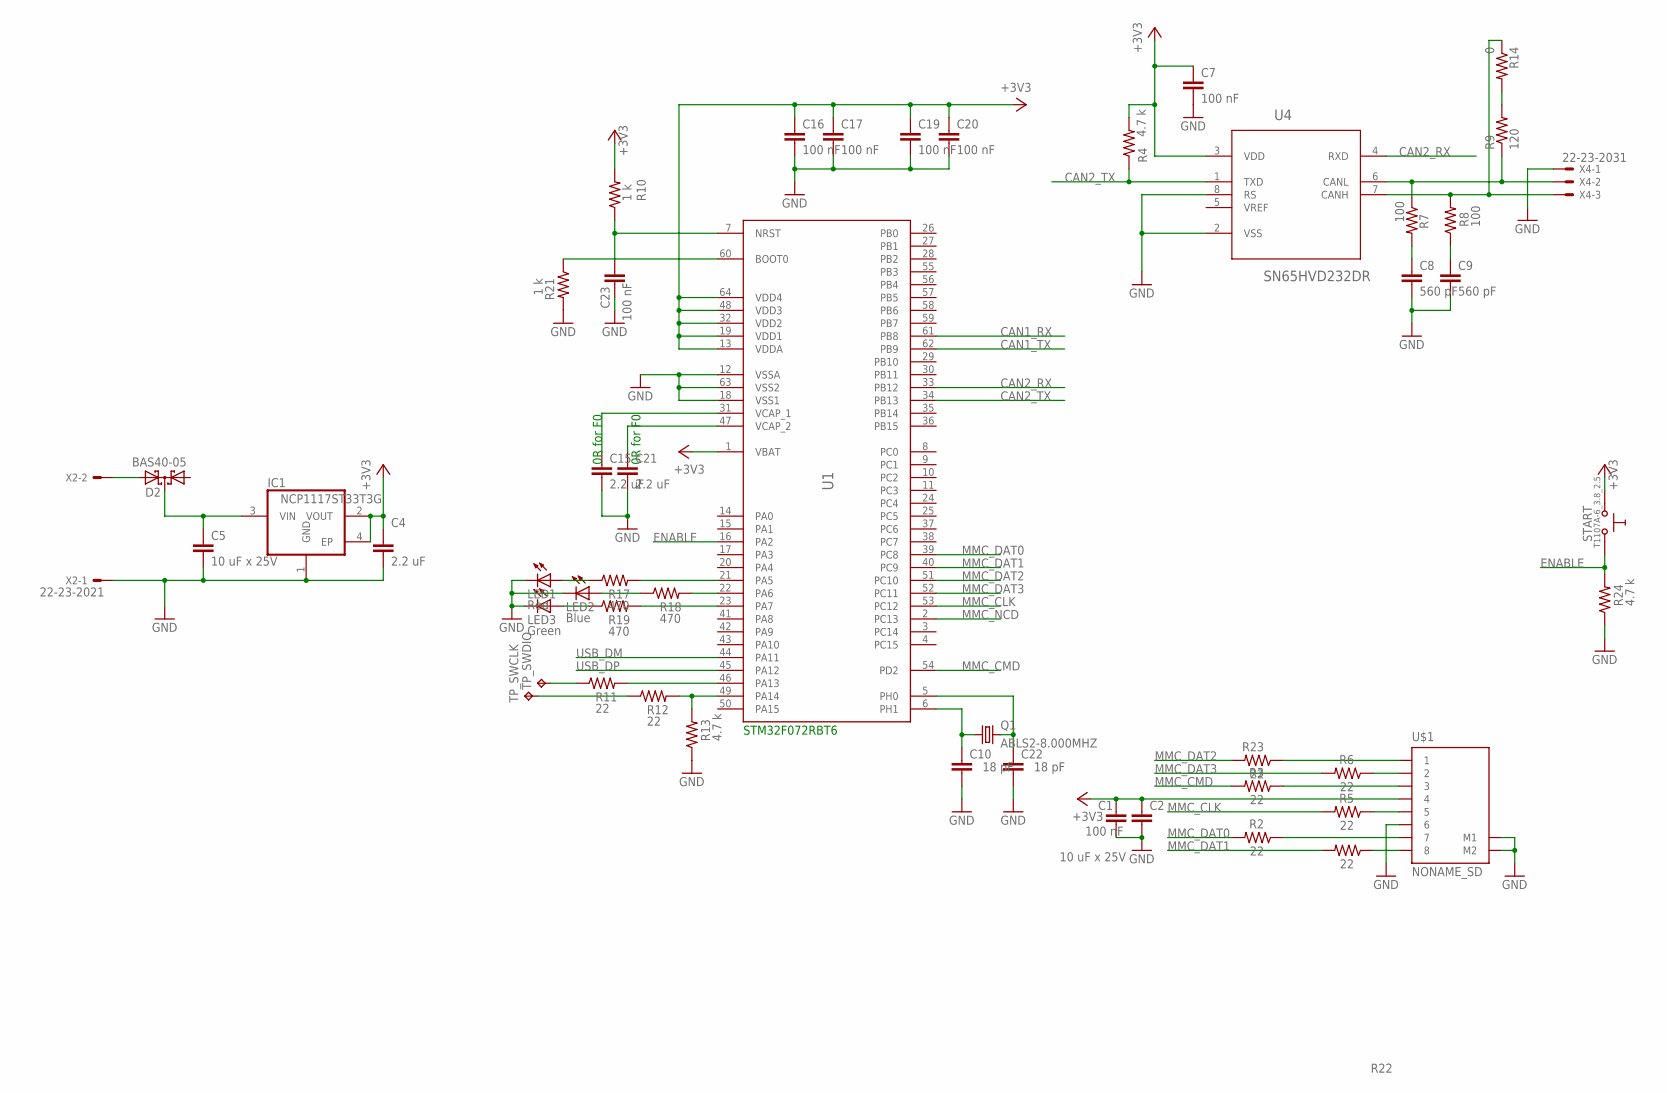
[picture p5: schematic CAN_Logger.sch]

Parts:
C1, C7, C16, C17, C19, C20, C23: 100 nF; C0603
C2, C5: 10 uF x 25V; C1206
C4, C15, C21: 2.2 uF; C0603
C8, C9: 560 pF; C0603
C10, C22: 18 pF; C0603
D2: BAS40-05; SOT23
IC1: NCP1117ST33T3G; SOT223
LED1: Red; LED_SML0603
LED2: Blue; LED_SML0603
LED3: Green; LED_SML0603
Q1: ABLS2-8.000MHZ; SM49
R2, R3, R5, R6, R11, R12, R22, R23: 22; R0603
R4, R13, R24: 4.7 k; R0603
R7, R8: 100; R0603
R9: 120; R0805
R10, R21: 1 k; R0603
R14: 0; R0201
R17, R18, R19: 470; R0603
START: T1107A-6_3.8_2.5; SW-TAKT_6X3.5_SMD
TP_SWCLK: TPTP10SQ; TP10SQ
TP_SWDIO: TPTP10SQ; TP10SQ
U1: STM32F405RGT6; LQFP64
U4: SN65HVD232DR; SOIC127P600X175-8N
U$1: NONAME_SD
X2: 22-23-2021
X4: 22-23-2031

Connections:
+3V3: C1.1, C2.1, C4.1, C7.1, C16.1, C17.1, C19.1, C20.1, IC1.2 (VOUT), IC1.4 (EP), R4.2, R10.2, START.P$1 (0), U1.1 (VBAT), U1.13 (VDDA), U1.19 (VDD1), U1.32 (VDD2), U1.48 (VDD3), U1.64 (VDD4), U4.3 (VDD), U$1.4
CAN1_RX: U1.61 (PB8)
CAN1_TX: U1.62 (PB9)
CAN2_RX: U1.33 (PB12), U4.4 (RXD)
CAN2_TX: R4.1, U1.34 (PB13), U4.1 (TXD)
ENABLE: R24.2, START.P$2 (1), U1.16 (PA2)
GND: C1.2, C2.2, C4.2, C5.2, C7.2, C8.2, C9.2, C10.2, C15.2, C16.2, C17.2, C19.2, C20.2, C21.2, C22.2, C23.2, IC1.1 (GND), LED1.C, LED2.C, LED3.C, R13.1, R21.2, R24.1, U1.12 (VSSA), U1.18 (VSS1), U1.63 (VSS2), U4.2 (VSS), U4.8 (RS), U$1.6, U$1.M1, U$1.M2, X2.1, X4.1
MMC_CLK: R5.2, U1.53 (PC12)
MMC_CMD: R3.2, U1.54 (PD2)
MMC_DAT0: R2.2, U1.39 (PC8)
MMC_DAT1: R22.2, U1.40 (PC9)
MMC_DAT2: R23.2, U1.51 (PC10)
MMC_DAT3: R6.2, U1.52 (PC11)
MMC_NCD: U1.2 (PC13)
unnamed: C15.1, U1.31 (VCAP_1)
unnamed: D2.2 (A2), X2.2
unnamed: R3.1, U$1.3
unnamed: R2.1, U$1.7
unnamed: R5.1, U$1.5
unnamed: R17.2, U1.21 (PA5)
unnamed: R7.1, R9.1, U4.6 (CANL), X4.2
unnamed: C5.1, D2.3 (C), IC1.3 (VIN)
unnamed: R8.2, R14.1, U4.7 (CANH), X4.3
unnamed: R6.1, U$1.2
unnamed: C8.1, R7.2
unnamed: C9.1, R8.1
unnamed: R18.2, U1.22 (PA6)
unnamed: R19.2, U1.23 (PA7)
unnamed: LED1.A, R17.1
unnamed: LED2.A, R18.1
unnamed: LED3.A, R19.1
unnamed: R22.1, U$1.8
unnamed: R23.1, U$1.1
unnamed: R11.2, U1.46 (PA13)
unnamed: R12.2, R13.2, U1.49 (PA14)
unnamed: C21.1, U1.47 (VCAP_2)
unnamed: R11.1, TP_SWDIO.TP
unnamed: R12.1, TP_SWCLK.TP
unnamed: C23.1, R10.1, U1.7 (NRST)
unnamed: R21.1, U1.60 (BOOT0)
unnamed: R9.2, R14.2
unnamed: C22.1, Q1.2, U1.5 (PH0)
unnamed: C10.1, Q1.1, U1.6 (PH1)
USB_DM: U1.44 (PA11)
USB_DP: U1.45 (PA12)

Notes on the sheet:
STM32F072RBT6
0R for F0

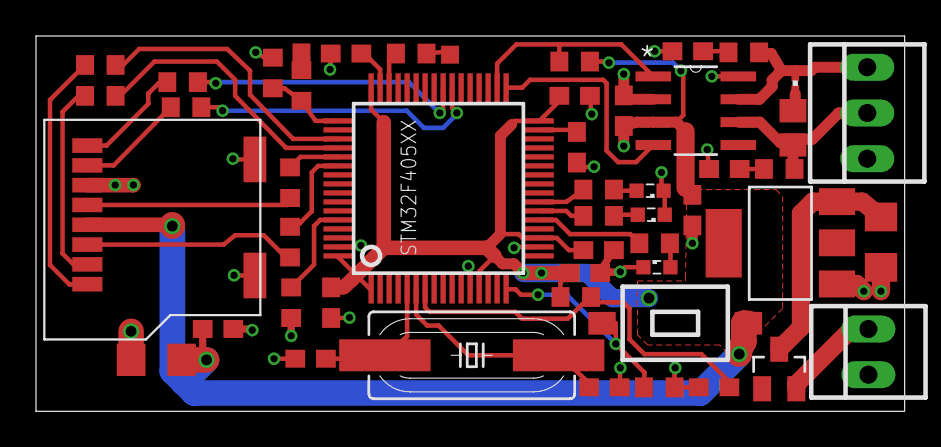
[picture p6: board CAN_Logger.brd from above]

Board: 2 copper layers, 48.3 x 20.8 mm, 50 parts (0 on the bottom side), 40 nets.

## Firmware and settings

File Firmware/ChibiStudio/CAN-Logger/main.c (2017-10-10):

/*
    ChibiOS/RT - Copyright (C) 2006-2013 Giovanni Di Sirio

    Licensed under the Apache License, Version 2.0 (the "License");
    you may not use this file except in compliance with the License.
    You may obtain a copy of the License at

        http://www.apache.org/licenses/LICENSE-2.0

    Unless required by applicable law or agreed to in writing, software
    distributed under the License is distributed on an "AS IS" BASIS,
    WITHOUT WARRANTIES OR CONDITIONS OF ANY KIND, either express or implied.
    See the License for the specific language governing permissions and
    limitations under the License.
*/

#include "ch.h"
#include "hal.h"

#include "ff.h"

#include "shell.h"


#include "file_utils.h"
#include <time.h>


// if defined, shell is using
//#define SHELL_EN


//#define INDICATE_IDLE_ON() palSetPad(GPIOA, GPIOA_PIN5_LED_R)
//#define INDICATE_IDLE_OFF() palClearPad(GPIOA, GPIOA_PIN5_LED_R)
#define INDICATE_IDLE_ON()
#define INDICATE_IDLE_OFF()

uint8_t bButton = 0;
unsigned char bLogging = 0; // if =1 than we logging to SD card

//------------------------------------------------------------------------------
// CAN instance configuration
static CANConfig cancfg = {
  CAN_MCR_ABOM | CAN_MCR_AWUM,
  CAN_BTR_SJW(0) | CAN_BTR_TS2(2) |
  CAN_BTR_TS1(1) | CAN_BTR_BRP(13)
};


//------------------------------------------------------------------------------

/*===========================================================================*/
// data bufferization functions

#define SD_WRITE_BUFFER             (1024*49)//(1024*21)   // 21K
#define SD_WRITE_BUFFER_FLUSH_LIMIT (1024*48)//(1024*20)   // 20K

#include <string.h>
//#include "mmcsd.h"

// buffer for collecting data to write
char sd_buffer[SD_WRITE_BUFFER];
WORD sd_buffer_length = 0;

// buffer for storing ready to write data
char sd_buffer_for_write[SD_WRITE_BUFFER];
unsigned char bReqWrite = 0; // write request, the sd_buffer is being copied to sd_buffer_for_write
WORD sd_buffer_length_for_write = 0;

unsigned char bWriteFault = 0; // in case of overlap or write fault


// fill buffer with spaces (before \r\n) to make it 512 byte size
// return 1 if filled and ready to write
int align_buffer()
{
  int i;
  int len;

  if (sd_buffer_length < 2) return 0;
  if (sd_buffer[sd_buffer_length-2] != '\r') return 0;
  if (sd_buffer[sd_buffer_length-1] != '\n') return 0;

  len = MMCSD_BLOCK_SIZE - (sd_buffer_length % MMCSD_BLOCK_SIZE);
  for (i = 0; i < len; i++)
    sd_buffer[sd_buffer_length + i - 2] = ' ';
  sd_buffer[sd_buffer_length - 2] = ',';
  sd_buffer[sd_buffer_length + len - 2] = '\r';
  sd_buffer[sd_buffer_length + len - 1] = '\n';

  sd_buffer_length += len;

  return 1;
}

// copy input buffer into the buffer for flash writing data
void copy_buffer()
{
  // request write operation
  memcpy(sd_buffer_for_write, sd_buffer, sd_buffer_length);
  sd_buffer_length_for_write = sd_buffer_length;
  sd_buffer_length = 0;
}

void request_write()
{
  if (bReqWrite)
    bWriteFault = 1; // buffer overlapping

  // request write operation
  align_buffer();
  copy_buffer();
  bReqWrite = 1;
}

int iLastWriteSecond = 0;
static struct tm timp;

void fwrite_string(char *pString)
{
  WORD length = strlen(pString);

  // Add string
  memcpy(&sd_buffer[sd_buffer_length], pString, length);
  sd_buffer_length += length;

  // Check flush limit
  if(sd_buffer_length >= SD_WRITE_BUFFER_FLUSH_LIMIT)
  {
    request_write();
  }
}





// file writing
FATFS SDC_FS;
FIL *file;
FRESULT fres;

int i;
int iSecond;
#define STRLINE_LENGTH 1024
char sLine[STRLINE_LENGTH];
systime_t stLastWriting;
unsigned char bIncludeTimestamp = 1;

void start_log()
{
  // open file and write the begining of the load
  rtcGetTime(&RTCD1, &timp);
  sprintf(sLine, "%04d-%02d-%02dT%02d-%02d-%02dZ.csv", timp.tm_year + 1900, timp.tm_mon, timp.tm_mday, timp.tm_hour, timp.tm_min, timp.tm_sec); // making new file

  file = fopen_(sLine, "a");
  if (bIncludeTimestamp)
    strcpy(sLine, "Timestamp,ID,Data0,Data1,Data2,Data3,Data4,Data5,Data6,Data7\r\n");
  else
    strcpy(sLine, "ID,Data0,Data1,Data2,Data3,Data4,Data5,Data6,Data7\r\n");
  fwrite_string(sLine);
  align_buffer();
  fwrite_(sd_buffer, 1, sd_buffer_length, file);
  f_sync(file);

  // reset buffer counters
  sd_buffer_length_for_write = 0;
  sd_buffer_length = 0;

  bWriteFault = 0;

  stLastWriting = chVTGetSystemTime(); // record time when we did write

  bLogging = 1;
}

int iFilterMask = 0;
int iFilterValue = 0;
unsigned char bLogStdMsgs = 1;
unsigned char bLogExtMsgs = 1;

int read_config_file()
{
  int value;
  char name[128];
  int baud;
  int res = 0;
  int ack = 0;

  iFilterMask = 0;
  iFilterValue = 0;
  bIncludeTimestamp = 1;
  bLogStdMsgs = 1;
  bLogExtMsgs = 1;


  // read file
  file = fopen_("Config.txt", "r");
  if (file == 0) return 0;

  while( f_gets(sLine, STRLINE_LENGTH, file) )
  {
    if (sscanf(sLine, "%s %d", name, &value) == 0)
    {
      continue;
    }

    if (strcmp(name, "baud") == 0)
    {
      baud = value;
      res = 1; // at least we got baudrate, config file accepted
    }
    else
    if (strcmp(name, "ack_en")  == 0)
    {
      ack = value;
    }
    else
    if (strcmp(name, "id_filter_mask")  == 0)
    {
      iFilterMask = value;
    }
    else
    if (strcmp(name, "id_filter_value")  == 0)
    {
      iFilterValue = value;
    }
    else
    if (strcmp(name, "timestamp")  == 0)
    {
      bIncludeTimestamp = value;
    }
    else
    if (strcmp(name, "log_std")  == 0)
    {
      bLogStdMsgs = value;
    }
    else
    if (strcmp(name, "log_ext")  == 0)
    {
      bLogExtMsgs = value;
    }
  }

  // configure CAN
  baud = (int)(7*baud/1000.0 + 0.5); // prescaler value
  if (ack)
    cancfg.btr =  CAN_BTR_SJW(0) | CAN_BTR_TS2(2) | CAN_BTR_TS1(1) | CAN_BTR_BRP(baud - 1);
  else
    cancfg.btr =  CAN_BTR_SJW(0) | CAN_BTR_TS2(2) | CAN_BTR_TS1(1) | CAN_BTR_BRP(baud - 1) | CAN_BTR_SILM; // silent mode flag
  canStop(&CAND2);
  canStart(&CAND2, &cancfg);
  fclose_(file);

  return res;
}

int init_sd()
{
  // initializing SDC interface
  sdcStart(&SDCD1, NULL);
  if (sdcConnect(&SDCD1) == HAL_FAILED)
  {
    //while (1) {  palTogglePad(GPIOA, GPIOA_PIN5_LED_R); chThdSleepMilliseconds(500); }
    return 0;
  }

  // mount the file system
  fres = f_mount(&SDC_FS, "/", 0);
  if (fres != FR_OK)
  {
    //while (1) {  palTogglePad(GPIOA, GPIOA_PIN5_LED_R); chThdSleepMilliseconds(500); }
    sdcDisconnect(&SDCD1);
    return 0;
  }

  return 1;
}
//------------------------------------------------------------------------------
/*
// 500kb -- work
static const CANConfig cancfg = {
  CAN_MCR_ABOM | CAN_MCR_AWUM,
  CAN_BTR_SJW(0) | CAN_BTR_TS2(2) |
  CAN_BTR_TS1(1) | CAN_BTR_BRP(13)
};
*/

char sTmp[128];

static THD_WORKING_AREA(can1_rx_wa, 256);
static msg_t can1_rx(void *p) {
  event_listener_t el;
  CANRxFrame rxmsg;

  (void)p;
  chRegSetThreadName("receiver can 1");
  chEvtRegister(&CAND2.rxfull_event, &el, 0);
  while(!chThdShouldTerminateX())
  {
    // if (chEvtWaitAnyTimeout(ALL_EVENTS, MS2ST(100)) == 0) continue;
    chEvtWaitAny(ALL_EVENTS);

    while (canReceive(&CAND2, CAN_ANY_MAILBOX, &rxmsg, TIME_IMMEDIATE) == MSG_OK)
    {
      /* Process message.*/

      if (bLogging)
      {
        // checking message acceptance
        if (rxmsg.IDE)
        {
          // message with extended ID received

          // are we accepting extended ID?
          if (!bLogExtMsgs) continue;

          // then check filter conditions
          if ((rxmsg.EID & iFilterMask) != (iFilterValue & iFilterMask)) continue;
        }
        else
        {
          // message with standard ID received

          // are we accepting standard ID?
          if (!bLogStdMsgs) continue;

          // then check filter conditions
          if ((rxmsg.SID & iFilterMask) != (iFilterValue & iFilterMask)) continue;
        }

        // write down data
        if (bIncludeTimestamp)
          sprintf(sTmp, "%d,%X", chVTGetSystemTime(), rxmsg.EID);
        else
          sprintf(sTmp, "%X", rxmsg.EID);

        for (i = 0; i < rxmsg.DLC; i++)
        {
          sprintf(sTmp+strlen(sTmp), ",%02X", rxmsg.data8[i]);
        }

        strcat(sTmp, "\r\n");
        fwrite_string(sTmp);
      }

      palTogglePad(GPIOA, GPIOA_PIN7_LED_G);
    }
  }
  chEvtUnregister(&CAND2.rxfull_event, &el);
  return 0;
}

//------------------------------------------------------------------------------
int iButtonStableCounter = 0;
unsigned char bButtonNew = 0;
unsigned char bButtonPrev = 0;
#define BUTTON_COUNTER_THRESHOLD 50000


/*
 * Application entry point.
 */
int main(void)
{
  #ifdef SHELL_EN
    Thread *shelltp = NULL;
  #endif
  unsigned char i,k;
  uint16_t *piData;
  int addr;
  CANTxFrame txmsg;
  //static struct tm timp;

  //FIL * file;


  halInit();
  chSysInit();

  palSetPad(GPIOA, GPIOA_PIN7_LED_G);

  //canSTM32SetFilters(0, 0, NULL);
  canStart(&CAND1, &cancfg);
  canStart(&CAND2, &cancfg);
  chThdCreateStatic(can1_rx_wa, sizeof(can1_rx_wa), NORMALPRIO + 7, can1_rx, NULL);
  /*
  while (1)
  {
    canTransmit(&CAND2, CAN_ANY_MAILBOX, &txmsg, MS2ST(100));
    chThdSleepMilliseconds(50);
  }
  */

  i = 0;
  while (TRUE)
  {
INDICATE_IDLE_ON();

    // maybe we need to write log, because we didnt for long time?
    if (chVTTimeElapsedSinceX(stLastWriting) > S2ST(2))
    {
      if (sd_buffer_length > 0) // there is data to write
      {
        // request write operation
        request_write();
      }
    }

    if (bReqWrite)
    {
        palSetPad(GPIOA, GPIOA_PIN6_LED_B);
INDICATE_IDLE_OFF();
        if (fwrite_(sd_buffer_for_write, 1, sd_buffer_length_for_write, file) != sd_buffer_length_for_write)
          bWriteFault = 2;
        if (f_sync(file) != FR_OK)
          bWriteFault = 2;
INDICATE_IDLE_ON();
        bReqWrite = 0;

        stLastWriting = chVTGetSystemTime(); // record time when we did write

        palClearPad(GPIOA, GPIOA_PIN6_LED_B);
    }

    // start-stop log button handling
    if (bButton && bButtonPrev == 0)
    {
      if (bLogging)
      {
        bLogging = 0;

        // we are in logging state -- should write the rest of log
        request_write();
      }
      else
      {
        // we are not logging -- opening SD card and starting log
        if (init_sd()) // trying to initialize sd card
        {
          if (read_config_file()) // trying to read configuration file
          {
            // all done -- start loging
            start_log();
          }
          else
          {
            palSetPad(GPIOA, GPIOA_PIN5_LED_R);
            palSetPad(GPIOA, GPIOA_PIN6_LED_B);
            //while (1) {  palTogglePad(GPIOA, GPIOA_PIN5_LED_R); chThdSleepMilliseconds(500); }
          }
        }
        else
        {
          palSetPad(GPIOA, GPIOA_PIN5_LED_R);
          //while (1) {  palTogglePad(GPIOA, GPIOA_PIN5_LED_R); chThdSleepMilliseconds(500); }
        }
      }
    }
    bButtonPrev = bButton;

    // this loop is going very fast, so the button filtering is needed
    bButtonNew = palReadPad(GPIOA, GPIOA_PIN2_BTN);
    if (bButtonNew && bButton == 0)
    {
      iButtonStableCounter++;
      if (iButtonStableCounter > BUTTON_COUNTER_THRESHOLD)
      {
        iButtonStableCounter = 0;
        bButton = 1;
      }
    }
    else
    if (bButtonNew == 0 && bButton)
    {
      iButtonStableCounter++;
      if (iButtonStableCounter > BUTTON_COUNTER_THRESHOLD)
      {
        iButtonStableCounter = 0;
        bButton = 0;
      }
    }
    else
      iButtonStableCounter = 0;

    if (bWriteFault)
    {
      palSetPad(GPIOA, GPIOA_PIN5_LED_R);
      //while (1) {  palTogglePad(GPIOA, GPIOA_PIN5_LED_R); chThdSleepMilliseconds(500); }
    }

  }
}
//------------------------------------------------------------------------------
// restart MCU and ChibiOS
void SoftReset()
{
  // http://www.chibios.org/dokuwiki/doku.php?id=chibios:howtos:stop_os
  // TODO:
}
//------------------------------------------------------------------------------

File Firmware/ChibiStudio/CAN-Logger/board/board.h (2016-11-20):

/*
    ChibiOS/RT - Copyright (C) 2006,2007,2008,2009,2010,
                 2011,2012 Giovanni Di Sirio.

    This file is part of ChibiOS/RT.

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
    You should have received a copy of the GNU General Public License
    along with this program.  If not, see <http://www.gnu.org/licenses/>.
*/

#ifndef _BOARD_H_
#define _BOARD_H_

/*
 * Setup for STMicroelectronics STM32F4-Discovery board.
 */

/*
 * Board identifier.
 */
#define BOARD_ST_STM32F4_DISCOVERY
#define BOARD_NAME                  "STMicroelectronics STM32F4-Discovery"


/*
 * Board oscillators-related settings.
 * NOTE: LSE not fitted.
 */
#if !defined(STM32_LSECLK)
#define STM32_LSECLK                32768
#endif

#if !defined(STM32_HSECLK)
#define STM32_HSECLK                8000000
#endif

/*
 * Ethernet PHY type.
 */
//#define BOARD_PHY_ID            MII_DP83848I_ID
#define BOARD_PHY_ID            0x0007C0F0  // LAN8720 ID code

#define BOARD_PHY_RMII

/*******************************************************************
 * CONNECTION LAYOUT BETWEEN ETH PHY DP83848 AND STM32F4DISCOVERY  *
 *******************************************************************
 *
 * PC1----------------MDC
 * PA2----------------MDIO
 * PA1----------------OSCIN
 * PA7----------------CRS
 * PC4----------------RX0
 * PC5----------------RX1
 * PB11---------------TX_EN
 * PB12---------------TX0
 * PB13---------------TX1
 *
 *
 */



/*
 * Board voltages.
 * Required for performance limits calculation.
 */
#define STM32_VDD                   300

/*
 * MCU type as defined in the ST header file stm32f4xx.h.
 */
#define STM32F405xx

/*
 * IO pins assignments.
 */
#define GPIOA_PIN0                0
#define GPIOA_PIN1_ETH_OSCIN        1 // ETH OSCIN
#define GPIOA_PIN2_BTN         2 // ETH MDIO
#define GPIOA_PIN3                  3
#define GPIOA_PIN4                  4
#define GPIOA_PIN5_LED_R                  5
#define GPIOA_PIN6_LED_B                  6
#define GPIOA_PIN7_LED_G          7 // ETH CRS
#define GPIOA_PIN8                  8
#define GPIOA_PIN_9              	 9
#define GPIOA_PIN_10             	 10
#define GPIOA_PIN11_CAN1_RX       		     11
#define GPIOA_PIN12_CAN1_TX       		     12
#define GPIOA_SWDIO                 13
#define GPIOA_SWCLK                 14
#define GPIOA_PIN15                 15

#define GPIOB_PIN0                  0
#define GPIOB_PIN1                  1
#define GPIOB_PIN2                  2
#define GPIOB_SWO                   3
#define GPIOB_PIN4                  4
#define GPIOB_PIN5                  5
#define GPIOB_PIN6_USART1_TX                   6
#define GPIOB_PIN7_USART1_RX                  7
#define GPIOB_PIN8                  8
#define GPIOB_SDA                   9
#define GPIOB_CLK_IN                10
#define GPIOB_PIN11_ETH_TX_EN       11 // ETH TX EN
#define GPIOB_PIN12_CAN2_RX         12 // ETH TX0
#define GPIOB_PIN13_CAN2_TX         13 // ETH TX1
#define GPIOB_PIN14                 14
#define GPIOB_PIN15                 15

#define GPIOC_OTG_FS_POWER_ON       0
#define GPIOC_PIN1_MDC              1 // ETH MDC
#define GPIOC_PIN2                  2
#define GPIOC_PDM_OUT               3
#define GPIOC_PIN4_ETH_RX0 			 4 // ETH RX0
#define GPIOC_PIN5_ETH_RX1          5 // ETH RX1
#define GPIOC_PIN6_USART6_TX                  6
#define GPIOC_PIN7_USART6_RX                  7
#define GPIOC_PIN8_SDIO_DAT0                  8
#define GPIOC_PIN9_SDIO_DAT1                  9
#define GPIOC_PIN10_SDIO_DAT2              10
#define GPIOC_PIN11_SDIO_DAT3              11
#define GPIOC_PIN12_SDIO_CLK                  12
#define GPIOC_PIN13                 13
#define GPIOC_PIN14                 14
#define GPIOC_PIN15                 15

#define GPIOD_PIN0                  0
#define GPIOD_PIN1                  1
#define GPIOD_PIN2_SDIO_CMD                  2
#define GPIOD_PIN3                  3
#define GPIOD_RESET                 4
#define GPIOD_PIN5_USART2_TX          5
#define GPIOD_PIN6_USART2_RX                  6
#define GPIOD_PIN7                  7
#define GPIOD_PIN8                  8
#define GPIOD_PIN9_USART3_RX                  9
#define GPIOD_PIN10                 10
#define GPIOD_PIN11                 11
#define GPIOD_PIN12        12
#define GPIOD_PIN13      13
#define GPIOD_PIN14         14
#define GPIOD_PIN15        15

#define GPIOE_INT1                  0
#define GPIOE_INT2                  1
#define GPIOE_PIN2                  2
#define GPIOE_CS_SPI                3
#define GPIOE_PIN4                  4
#define GPIOE_PIN5                  5
#define GPIOE_PIN6                  6
#define GPIOE_PIN7                  7
#define GPIOE_PIN8                  8
#define GPIOE_PIN9                  9
#define GPIOE_PIN10                 10
#define GPIOE_PIN11                 11
#define GPIOE_PIN12                 12
#define GPIOE_PIN13                 13
#define GPIOE_PIN14                 14
#define GPIOE_PIN15                 15
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

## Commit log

2016-11-25 baudrate bug fixed, use case test data added
    [Config.txt, log.csv, log_.csv]
2017-01-18 updated to hardware revision 2
    [CAN_Logger.brd, CAN_Logger.sch]
2018-01-05 extended ID fix
    also full header line
    [main.c]
2018-07-16 additional configuartion options for start/stop logs implemented
    start_on_power, circular_write, start_id, stop_id, start_on_CAN, stop_on_CAN, start_frame_to_name
    [CAN_Logger.GBL, CAN_Logger.GBO, CAN_Logger.GBP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]
2018-07-23 reverted back to 8.3, gap detection in file names (under wraping)
    [main.c]
